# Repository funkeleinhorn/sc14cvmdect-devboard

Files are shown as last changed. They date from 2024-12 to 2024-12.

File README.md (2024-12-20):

# SC14CVMDECT Devboard

Open Hardware devboard for the [SC14CVMDECT](https://www.renesas.com/en/products/wireless-connectivity/dect/sc14cvmdect-cordless-voice-module) module from Renesas.
Documentation of the devboard and the existing Open Source Software implementations for the SC14CVMDECT module can be found at [redected.org](https://redected.org).

This project is licensed as open hardware. See LICENSE.txt for details.

## Images

Here you can see how the PCB looks:

top
bottom

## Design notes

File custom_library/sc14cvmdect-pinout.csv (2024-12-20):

Name | SC14CVMDECT
Reference | U
Datasheet | https://4donline.ihs.com/images/VipMasterIC/IC/RNCC/RNCC-S-A0015592214/RNCC-S-A0015785019-1.pdf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
Description | The SC14CVMDECT SF is a member of the Cordless Module family with integrated radio transceiver and baseband processor in a single package. It is designed for hosted and embedded cordless voice and data applications in the DECT frequency band. Its simple to use API commands allow easy setup of a wireless link between two or more nodes.
Keywords | DECT, RF, TELEPHONY
Footprint
Footprint Filter
PIN | Name | Type | Side | Description
63,64 | VBATIN | power_in | top | Main supply voltage < 3.45 V.
25 | VDDPA | power_in | top | CLASSD Audio Amplifier supply voltage up to 3.45 V.GND or leave unconnected if CLASSD Audio Amplifier is not used.
1,6,14,28,38,45,49-51,60,70-72,74,76-78,80 | GND | power_in | bottom
11 | VREFm | power_out | bottom | Negative microphone reference (star point), connect to GND.
29 | PON/P1[6] | input | left | Power on, Switches on the device if Voltage > 1.5 V. May be directly connected to VBAT, also with Li-Ion batteries.After startup the software takes over then PON pin to keep the device on after which the PON pin may be released.
 |  | space | left
52 | RSTn | input | left | Active low Reset input with Schmitt-trigger input, open-drain output. Input may not exceed 2.0 V. An internal capacitor of 47 nF is mounted on this pin.
 |  | space | left
53 | JTAG | bidirectional | left | JTAG-SDI+ | one wire Debug interface with open-drain.
 |  | space | left
40 | SPI_DI/PWM1/P0[7] | bidirectional | left | I/O Port SPI Data Input
41 | SPI_DO/P0[6] | bidirectional | left | I/O Port SPI Data Out
42 | SPI_CLK/P0[5] | bidirectional | left | I/O Port SPI Clock
43 | SPI_EN/P0[4] | bidirectional | left | I/O port SPI_EN: Active low.
 |  | space | left
44 | SCL2/URX2/P0[3] | bidirectional | left | I/O port Access bus clock, UART Serial In.
46 | SDA2/UTX2/P0[2] | bidirectional | left | I/O port Access bus data, UART Serial Out.
 |  | space | left
47 | URX/PWM0/P0[1] | bidirectional | left | I/O port UART Serial In
48 | UTX/P0[0] | output | left | I/O Port UART Serial Out
 |  | space | left
54 | PCM_FSC/SF/P2[5] | bidirectional | left | I/O Port PCM_FSC: PCM Frame Sync
55 | PCM_DO/SCL1/DP3/P2[4] | bidirectional | left | "I/O port SCL1; I2C clock PCM_DO: PCM Data output"
56 | PCM_DI/SDA1/DP2/P2[3] | bidirectional | left | I/O Port SDA1: I2C Data PCM_DI: PCM Data input
57 | PCM_CLK/P2[2] | bidirectional | left | I/O Port PCM_CLK: PCM clock input/output
 |  | space | left
58 | LED4/PM1/P2[1] | bidirectional | left | I/O Port PWM1: Pulse Width Modulation output LED4: 2.5 mA/5 mA LED current sink
59 | LED3/PM0/P2[0] | bidirectional | left | I/O Port PWM0: - LED3: 2.5 mA/5 mA LED current sink
 |  | space | left
30 | ULP_XTAL | input | left | 32.768 kHz XTAL clock input. Connect to GND if not used. (Note 6)
31 | ULP_PORT | input | left | Ultra Low Power Port Pin. Connect to GND if not used. (Note 6)
 |  | space | left
2 | P0 | output | left | Control port for FAD. See 4.13
4 | P0n | output | left | Control port for FAD. See 4.13
3 | RFP0 | output | left | Control port for FAD. See 4.13
5 | RFP0n | output | left | Control port for FAD. See 4.13
7 | VREFp | power_out | right | Positive microphone supply voltage
8 | MICp/CIDINn | input | right | Positive microphone input
9 | MICn/CIDOUT | input | right | Negative handset microphone input
10 | MICh/LINEIN | input | right | Headset microphone input with fixed input protection
 |  | space | right
12 | LSRp/LINEOUT/AGND | output | right | Positive handset loudspeaker output
13 | LSRn/LINEOUT/AGND | output | right | Negative handset loudspeaker output
 |  | space | right
24 | PAOUTp/DP1/P3[1] | bidirectional | right | External/Big loudspeaker positive outputs
27 | PAOUTn/DP0/P3[0] | bidirectional | right | External/Big loudspeaker positive output
 |  | space | right
65 | CIDINp/P3[2] | bidirectional | right | I/O Port
66 | RINGp/P3[7] | bidirectional | right | I/O Port
67 | RINGn/P3[6] | bidirectional | right | I/O Port
68 | RINGING/RINGOUT/P3[5] | bidirectional | right | I/O Port
69 | PARADET/P3[4] | bidirectional | right | I/O Port
 |  | space | right
15 | ADC0/P3[3] | bidirectional | right | I/O Port
16 | ADC1/INT0/P1[0] | bidirectional | right | I/O Port
 |  | space | right
17 | SOCp | input | right | Battery state of charge positive input. Connect to GND if not used. See 4.9
18 | SOCn | input | right | Battery state of charge negative input. Star point connected to the SOC resistor. Connect to GND if not used. See 4.9
19 | DC_SENSE | input | right | Voltage sense input. Connect to GND if not used.
20 | DC_I | input | right | Current sense input of DC/DC converter. Connect to GND if not used
21 | DC_CTRL | output | right | Switching clock for the DC/DC converter.
22 | CHARGE_CTRL | output | right | Charge control pin.Leave unconnected if not used. See 4.9
23 | CHARGE/P1[7] | input | right | Charger connected indication. Switches on the device if voltage > 1.5 V. Must be connected to charger via resistor R > (Vcharger_max-3 V)/10 mA (round to next largest value in range). See 4.9
26 | CP_VOUT1 | output | right | Charge Pump Output 1.A capacitor of 1 F to GND is internally connected to this pin.
 |  | space | right
32 | BXTAL/INT7/P2[7] | bidirectional | right | I/O port
33 | VDDE/RDI/INT5/P1[5] | bidirectional | right | I/O Port
34 | TDOD/INT4/P1[4] | bidirectional | right | I/O port
35 | SIO/INT3/P1[3] | bidirectional | right | I/O Port
36 | SK/INT2/P1[2] | bidirectional | right | I/O Port
37 | LE/INT1/P1[1] | bidirectional | right | I/O Port
39 | WTF_IN/P2[6] | bidirectional | right | I/O port
 |  | space | right
73 | RF1 | input | right | RF signal for external antenna. See 4.13
75 | RF0 | input | right | RF signal for external antenna. See 4.13
79 | TP1 | input | right | Tuning point for internal antenna. Follow instructions of Section 8.5.
 |  | space | right
61 | VDDOUT | no_connect | right | Test purpose only. Must be left unconnected.
62 | VBATS | no_connect | right | Test purpose only. Must be left unconnected.
81 | TP2 | no_connect | right | Must be left unconnected. See section 8.3.2 and Figure 36.
82 | TP3 | no_connect | right | Must be left unconnected. See section 8.3.2 and Figure 36.
83 | TP4 | no_connect | right | Must be left unconnected. See section 8.3.2 and Figure 36.
84 | TP5 | no_connect | right | Must be left unconnected. See section 8.3.2 and Figure 36.
85 | TP6 | no_connect | right | Must be left unconnected. See section 8.3.2 and Figure 36.
86 | TP7 | no_connect | right | Must be left unconnected. See section 8.3.2 and Figure 36.
87 | TP8 | no_connect | right | Must be left unconnected. See section 8.3.2 and Figure 36.
88 | TP9 | no_connect | right | Must be left unconnected. See section 8.3.2 and Figure 36.

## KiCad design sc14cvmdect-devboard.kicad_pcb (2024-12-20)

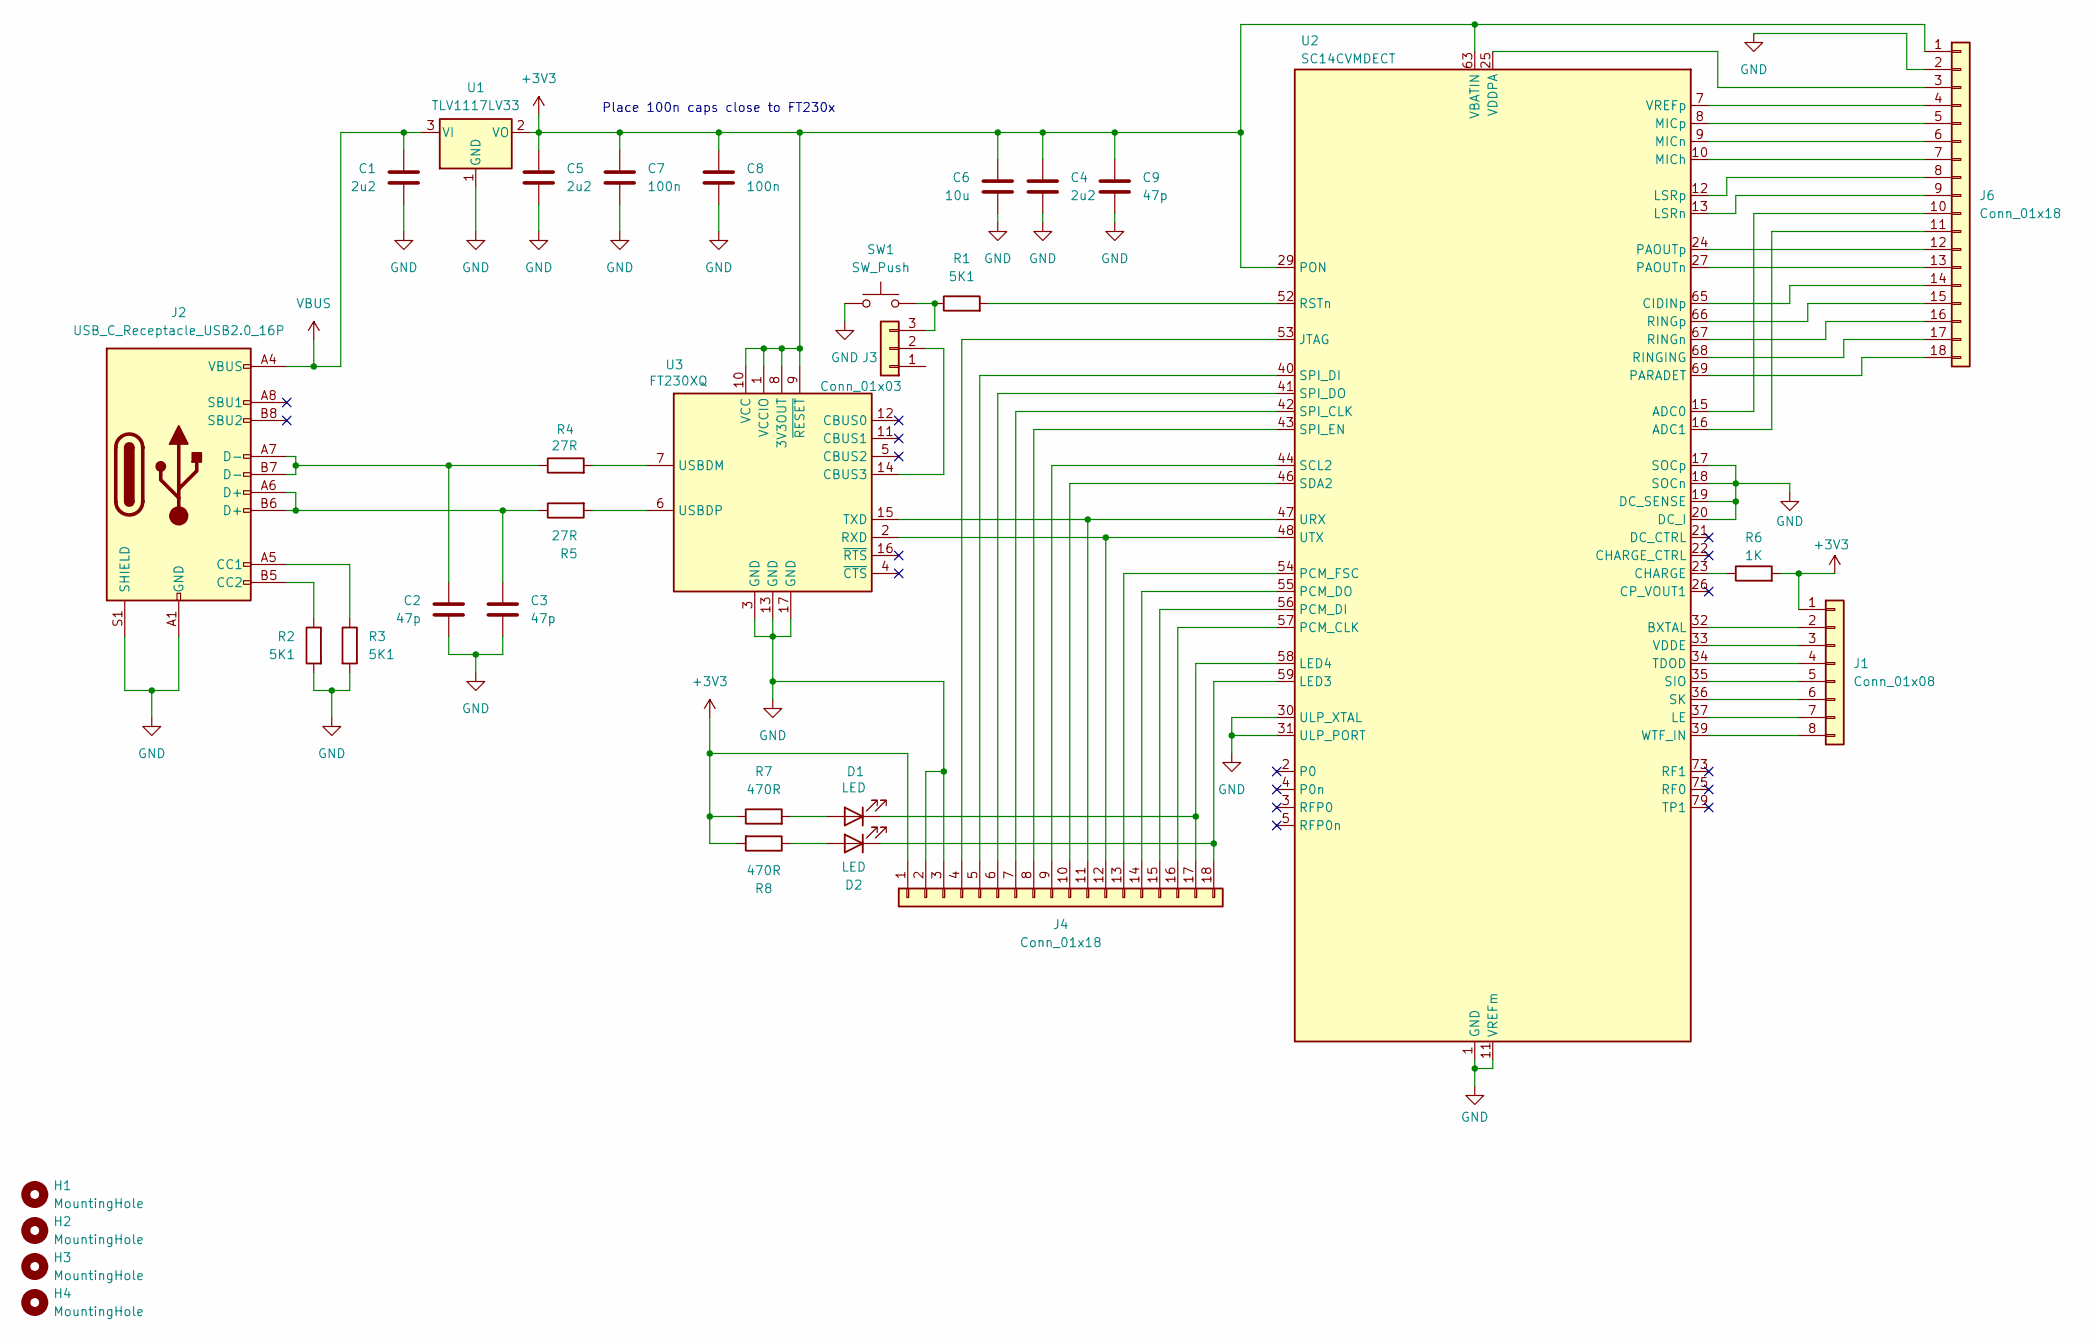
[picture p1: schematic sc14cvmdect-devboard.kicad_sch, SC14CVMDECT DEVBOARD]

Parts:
C1, C4, C5: 2u2; C_0805_2012Metric
C2, C3: 47p; C_0603_1608Metric
C6: 10u; C_0805_2012Metric
C7, C8: 100n; C_0603_1608Metric
C9: 47p; R_0603_1608Metric
D1, D2: LED; LED_0603_1608Metric
H1, H2, H3, H4: MountingHole; MountingHole_3.2mm_M3_DIN965
J1: Conn_01x08; PinHeader_1x08_P2.54mm_Vertical
J2: USB_C_Receptacle_USB2.0_16P; USB_C_Receptacle_JAE_DX07S016JA1R1500
J3: Conn_01x03; PinHeader_1x03_P2.54mm_Vertical
J4, J6: Conn_01x18; PinHeader_1x18_P2.54mm_Vertical
R1, R2, R3: 5K1; R_0603_1608Metric
R4, R5: 27R; R_0603_1608Metric
R6: 1K; R_0603_1608Metric
R7, R8: 470R; R_0603_1608Metric
SW1: SW_Push; SW_SPST_PTS647_Sx70
U1: TLV1117LV33; SOT-223-3_TabPin2
U2: SC14CVMDECT
U3: FT230XQ; QFN-16-1EP_4x4mm_P0.65mm_EP2.1x2.1mm

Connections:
+3V3: C4.1, C5.1, C6.1, C7.1, C8.1, C9.1, J1.1, J4.1, J6.1, R6.2, R7.1, R8.2, U1.2 (VO), U2.29 (PON), U2.63 (VBATIN), U2.64 (VBATIN), U3.1 (VCCIO), U3.8 (3V3OUT), U3.9 (~RESET), U3.10 (VCC)
GND: C1.2, C2.2, C3.2, C4.2, C5.2, C6.2, C7.2, C8.2, C9.2, J2.A1 (GND), J2.A12 (GND), J2.B1 (GND), J2.B12 (GND), J2.S1 (SHIELD), J4.2, J4.3, J6.2, R2.2, R3.2, SW1.1, U1.1 (GND), U2.1 (GND), U2.6 (GND), U2.11 (VREFm), U2.14 (GND), U2.17 (SOCp), U2.18 (SOCn), U2.19 (DC_SENSE), U2.20 (DC_I), U2.28 (GND), U2.30 (ULP_XTAL), U2.31 (ULP_PORT), U2.38 (GND), U2.45 (GND), U2.49 (GND), U2.50 (GND), U2.51 (GND), U2.60 (GND), U2.70 (GND), U2.71 (GND), U2.72 (GND), U2.74 (GND), U2.76 (GND), U2.77 (GND), U2.78 (GND), U2.80 (GND), U3.3 (GND), U3.13 (GND), U3.17 (GND)
unnamed: C2.1, J2.A7 (D-), J2.B7 (D-), R4.1
unnamed: C3.1, J2.A6 (D+), J2.B6 (D+), R5.1
unnamed: D1.2 (A), R7.2
unnamed: D1.1 (K), J4.17, U2.58 (LED4)
unnamed: D2.2 (A), R8.1
unnamed: D2.1 (K), J4.18, U2.59 (LED3)
unnamed: J1.2, U2.32 (BXTAL)
unnamed: J1.3, U2.33 (VDDE)
unnamed: J1.4, U2.34 (TDOD)
unnamed: J1.5, U2.35 (SIO)
unnamed: J1.6, U2.36 (SK)
unnamed: J1.7, U2.37 (LE)
unnamed: J1.8, U2.39 (WTF_IN)
unnamed: J2.A5 (CC1), R3.1
unnamed: J2.B5 (CC2), R2.1
unnamed: J3.2, U3.14 (CBUS3)
unnamed: J3.3, R1.1, SW1.2
unnamed: J4.4, U2.53 (JTAG)
unnamed: J4.5, U2.40 (SPI_DI)
unnamed: J4.6, U2.41 (SPI_DO)
unnamed: J4.7, U2.42 (SPI_CLK)
unnamed: J4.8, U2.43 (SPI_EN)
unnamed: J4.9, U2.44 (SCL2)
unnamed: J4.10, U2.46 (SDA2)
unnamed: J4.11, U2.47 (URX), U3.15 (TXD)
unnamed: J4.12, U2.48 (UTX), U3.2 (RXD)
unnamed: J4.13, U2.54 (PCM_FSC)
unnamed: J4.14, U2.55 (PCM_DO)
unnamed: J4.15, U2.56 (PCM_DI)
unnamed: J4.16, U2.57 (PCM_CLK)
unnamed: J6.3, U2.25 (VDDPA)
unnamed: J6.4, U2.7 (VREFp)
unnamed: J6.5, U2.8 (MICp)
unnamed: J6.6, U2.9 (MICn)
unnamed: J6.7, U2.10 (MICh)
unnamed: J6.8, U2.12 (LSRp)
unnamed: J6.9, U2.13 (LSRn)
unnamed: J6.10, U2.15 (ADC0)
unnamed: J6.11, U2.16 (ADC1)
unnamed: J6.12, U2.24 (PAOUTp)
unnamed: J6.13, U2.27 (PAOUTn)
unnamed: J6.14, U2.65 (CIDINp)
unnamed: J6.15, U2.66 (RINGp)
unnamed: J6.16, U2.67 (RINGn)
unnamed: J6.17, U2.68 (RINGING)
unnamed: J6.18, U2.69 (PARADET)
unnamed: R6.1, U2.23 (CHARGE)
unnamed: R1.2, U2.52 (RSTn)
unnamed: R4.2, U3.7 (USBDM)
unnamed: R5.2, U3.6 (USBDP)
VBUS: C1.1, J2.A4 (VBUS), J2.A9 (VBUS), J2.B4 (VBUS), J2.B9 (VBUS), U1.3 (VI)

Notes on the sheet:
Place 100n caps close to FT230x

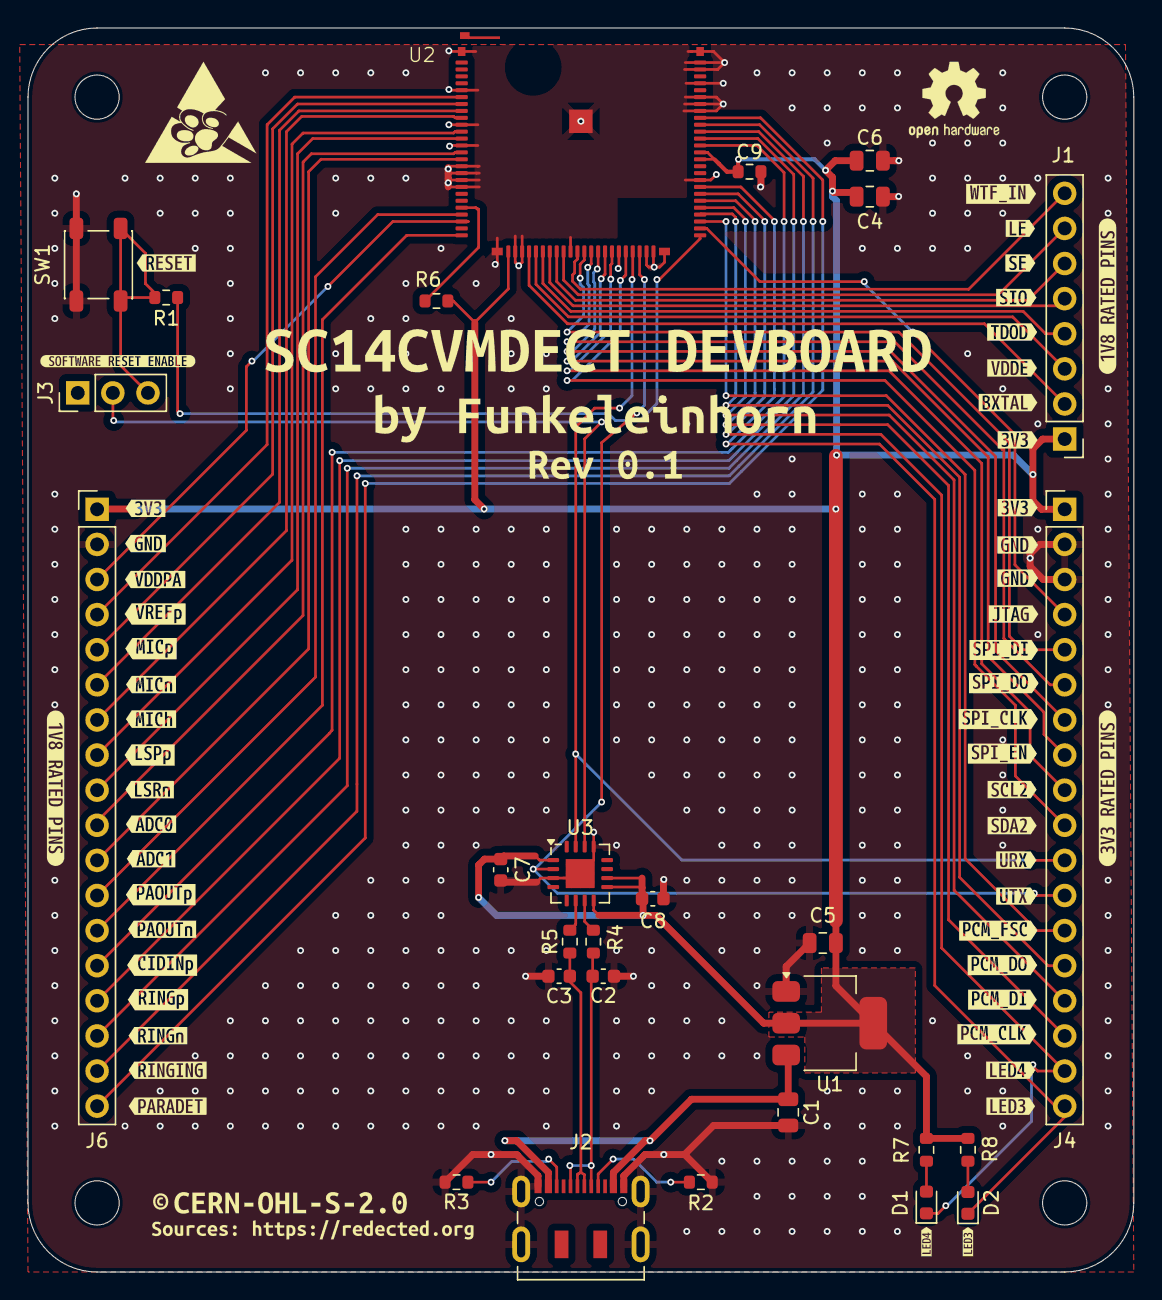
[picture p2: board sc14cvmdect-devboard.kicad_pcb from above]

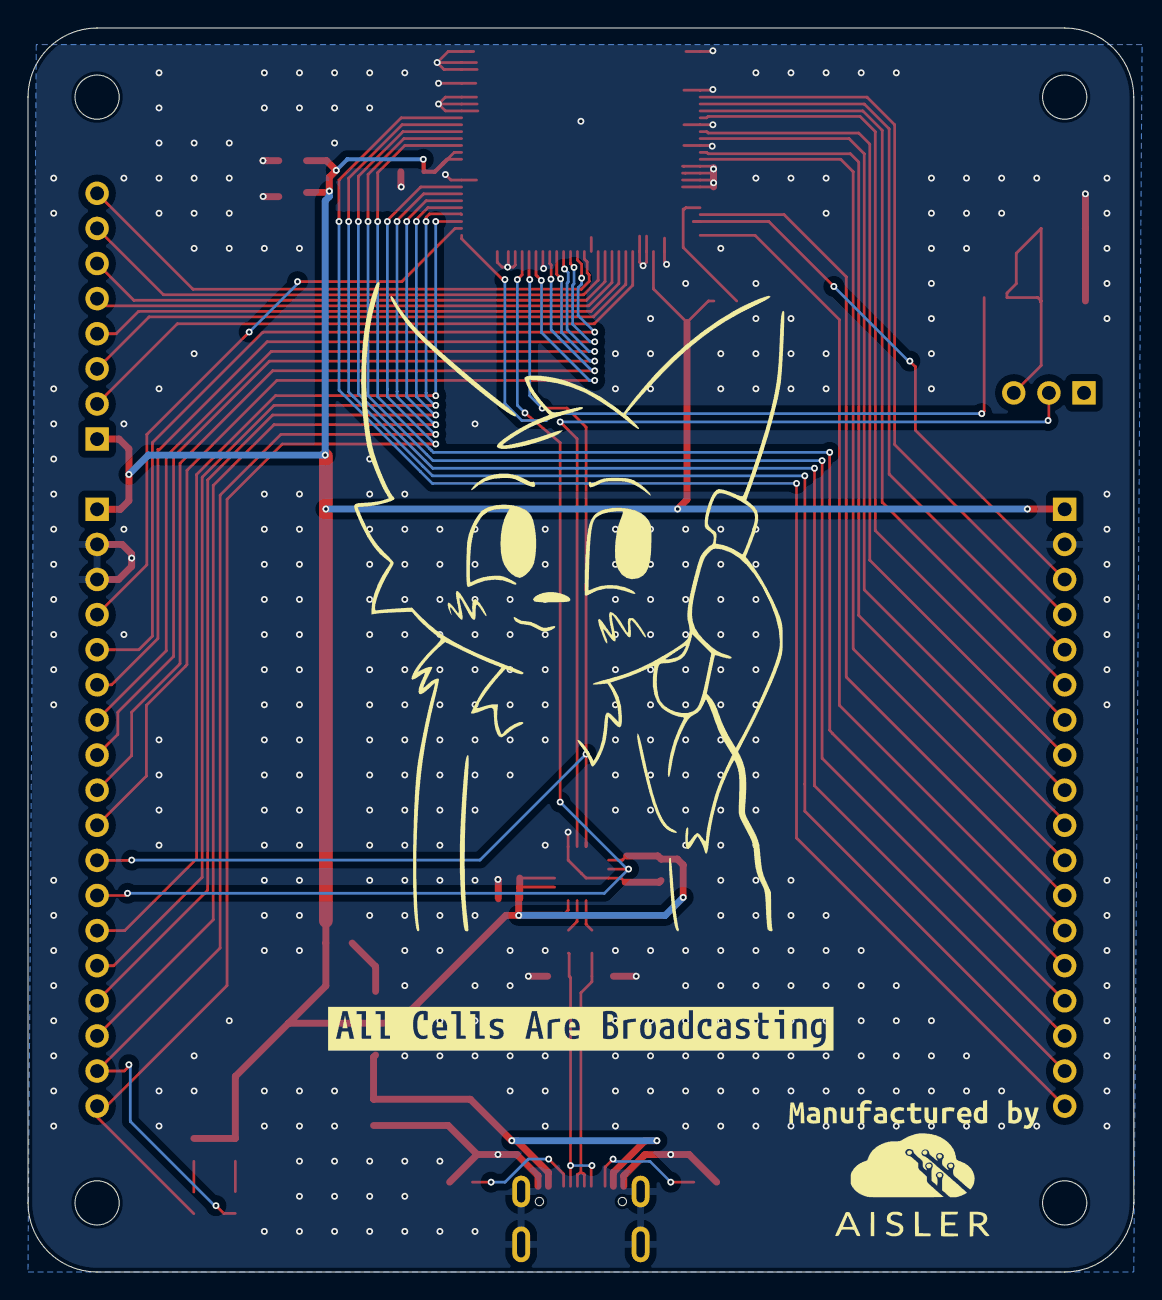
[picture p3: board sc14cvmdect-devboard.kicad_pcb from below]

Board: 4 copper layers, 80.0 x 90.0 mm, 91 parts (2 on the bottom side), 53 nets.

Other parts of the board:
kibuzzard-67575DB5: G***; kibuzzard-67575DB5
kibuzzard-67575DD6: G***; kibuzzard-67575DD6
kibuzzard-67575DF0: G***; kibuzzard-67575DF0
kibuzzard-67575E60: G***; kibuzzard-67575E60
kibuzzard-67575EB8: G***; kibuzzard-67575EB8
kibuzzard-67575F62: G***; kibuzzard-67575F62
kibuzzard-67575F78: G***; kibuzzard-67575F78
kibuzzard-67576AD7: G***; kibuzzard-67576AD7
kibuzzard-67576C4F: G***; kibuzzard-67576C4F
kibuzzard-67576C6D: G***; kibuzzard-67576C6D
kibuzzard-67576C73: G***; kibuzzard-67576C73
kibuzzard-67576CB2: G***; kibuzzard-67576CB2
kibuzzard-675753CF: G***; kibuzzard-675753CF
kibuzzard-675756D3: G***; kibuzzard-675756D3
kibuzzard-675758CB: G***; kibuzzard-675758CB
kibuzzard-675760A1: G***; kibuzzard-675760A1
kibuzzard-675760B0: G***; kibuzzard-675760B0
kibuzzard-675761BC: G***; kibuzzard-675761BC
kibuzzard-675761D3: G***; kibuzzard-675761D3
kibuzzard-675761E9: G***; kibuzzard-675761E9
kibuzzard-675763C9: G***; kibuzzard-675763C9
kibuzzard-675763D6: G***; kibuzzard-675763D6
kibuzzard-675763F4: G***; kibuzzard-675763F4
kibuzzard-675764D8: G***; kibuzzard-675764D8
kibuzzard-675765AC: G***; kibuzzard-675765AC
kibuzzard-675765C1: G***; kibuzzard-675765C1
kibuzzard-675765D1: G***; kibuzzard-675765D1
kibuzzard-6757604E: G***; kibuzzard-6757604E
kibuzzard-6757607D: G***; kibuzzard-6757607D
kibuzzard-6757616E: G***; kibuzzard-6757616E
kibuzzard-6757620D: G***; kibuzzard-6757620D
kibuzzard-6757621E: G***; kibuzzard-6757621E
kibuzzard-6757634F: G***; kibuzzard-6757634F
kibuzzard-6757635E: G***; kibuzzard-6757635E
kibuzzard-6757636C: G***; kibuzzard-6757636C
kibuzzard-6757638A: G***; kibuzzard-6757638A
kibuzzard-6757639A: G***; kibuzzard-6757639A
kibuzzard-6757652F: G***; kibuzzard-6757652F
kibuzzard-6757657B: G***; kibuzzard-6757657B
kibuzzard-6757659F: G***; kibuzzard-6757659F
kibuzzard-6757660D: G***; kibuzzard-6757660D
kibuzzard-6757661A: G***; kibuzzard-6757661A
kibuzzard-6757663B: G***; kibuzzard-6757663B
kibuzzard-67575390: G***; kibuzzard-67575390
kibuzzard-67575747: G***; kibuzzard-67575747
kibuzzard-67576033: G***; kibuzzard-67576033
kibuzzard-67576075: G***; kibuzzard-67576075
kibuzzard-67576138: G***; kibuzzard-67576138
kibuzzard-67576147: G***; kibuzzard-67576147
kibuzzard-67576184: G***; kibuzzard-67576184
kibuzzard-67576478: G***; kibuzzard-67576478
kibuzzard-67576487: G***; kibuzzard-67576487
kibuzzard-67576490: G***; kibuzzard-67576490
kibuzzard-67576547: G***; kibuzzard-67576547
kibuzzard-67576569: G***; kibuzzard-67576569
kibuzzard-67576627: G***; kibuzzard-67576627
kibuzzard-67576652: G***; kibuzzard-67576652
kibuzzard-67576660: G***; kibuzzard-67576660
kibuzzard-67577969: G***; kibuzzard-67577969

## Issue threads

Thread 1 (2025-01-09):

I created (half) a 3D printable case

dzervas, 2025-01-09:
Hey I used kikit to generate a DXF of the board and used it to create a 3D printable case - only the bottom part for now.

Here's how it looks:
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

Here's the onShape link: https://cad.onshape.com/documents/cfe39e9a8b7097843658ea15/w/36a87dd0a1ce688bce869485/e/d59420b6fb7861c7f7ca88e8

Here's the exported STL:
[bottom.zip](https://github.com/user-attachments/files/18360006/bottom.zip)

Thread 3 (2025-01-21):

Can we rename the default branch to "main"?

Mimoja, 2025-01-21:
It is a usually a no-op and is a small but powerfull statement

funkeleinhorn, 2025-01-22:
Renamed the branch and fixed up the references to it :)

Closed 2025-01-22.
